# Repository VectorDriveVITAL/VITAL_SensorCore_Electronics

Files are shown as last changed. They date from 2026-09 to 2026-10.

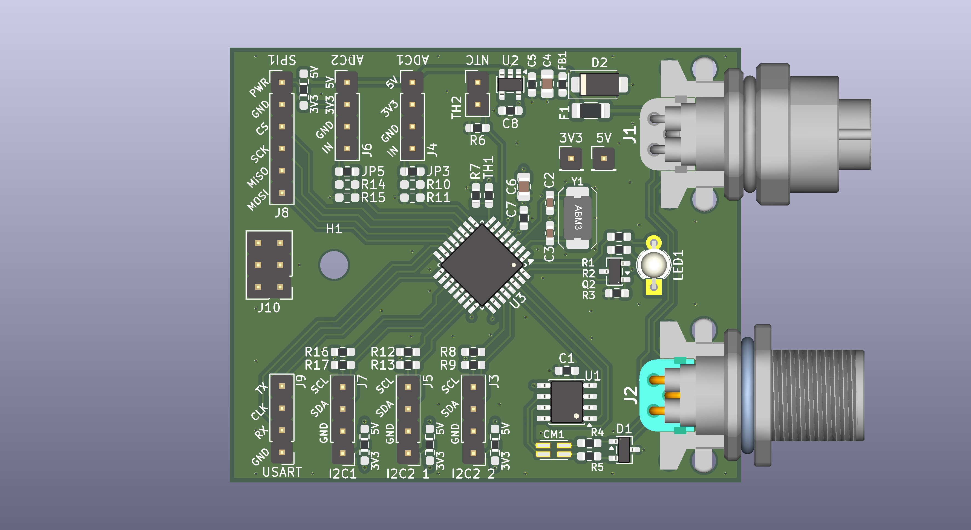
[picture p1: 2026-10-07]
SensorPack_v1/SensorPack_v1.png

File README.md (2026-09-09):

# [Project Name] — VITAL PCB Repository

Centralized repository for all PCB's for VECTOR Drive's PCB work.

## Boards

| Board | Function | Status |
|---|---|---|
| `CapstonePractice` | Practice board for planning around STM32C092 | Practice |
| `SensorCore_v1` | V1 of Sensor Core board | Schematic/PCB partially done |
| `SensorPack_v1` | V1 of Sensor Core board | Schematic partially done |

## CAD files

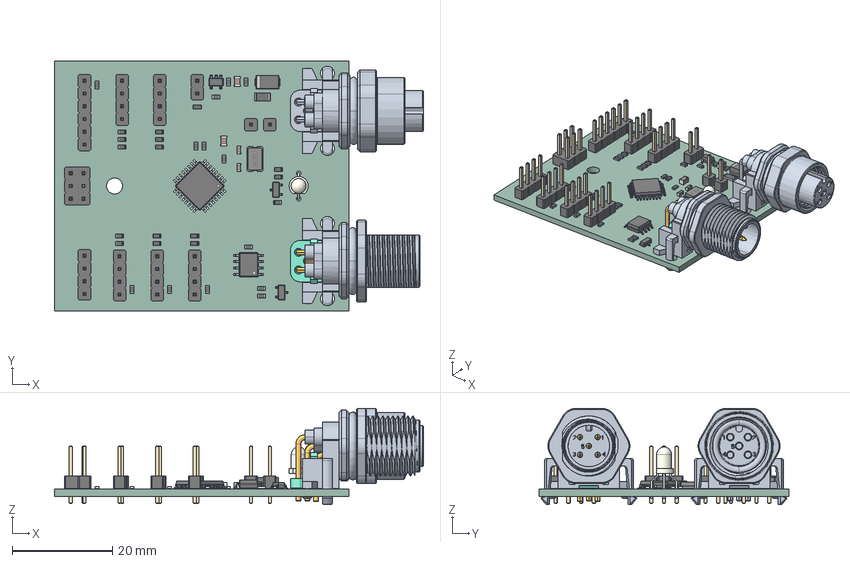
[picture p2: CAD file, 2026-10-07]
SensorPack_v1/SensorPack_v1.step
73.7 x 50.0 x 19.2 mm
R_0603_1608Metric x 29
PinHeader_2x03_P254mm_Vertical
PinHeader_1x06_P254mm_Vertical
D_SMA
SOT-23-3 x 2
PinHeader_1x04_P254mm_Vertical x 6
C_0603_1608Metric x 2
LED_D3.0mm-3
M12A-05PMMR-SF7003_SW0001
M12A-05PFFR-SF7003_SW0001
C_0805_2012Metric x 2
SOT-23-5
PinHeader_1x01_P254mm_Vertical x 2
LQFP-32_7x7mm_P0.8mm
PinHeader_1x02_P254mm_Vertical
SOIC-8_3.9x4.9mm_P1.27mm
ABM3
R_1206_3216Metric
SensorPack_v1_PCB

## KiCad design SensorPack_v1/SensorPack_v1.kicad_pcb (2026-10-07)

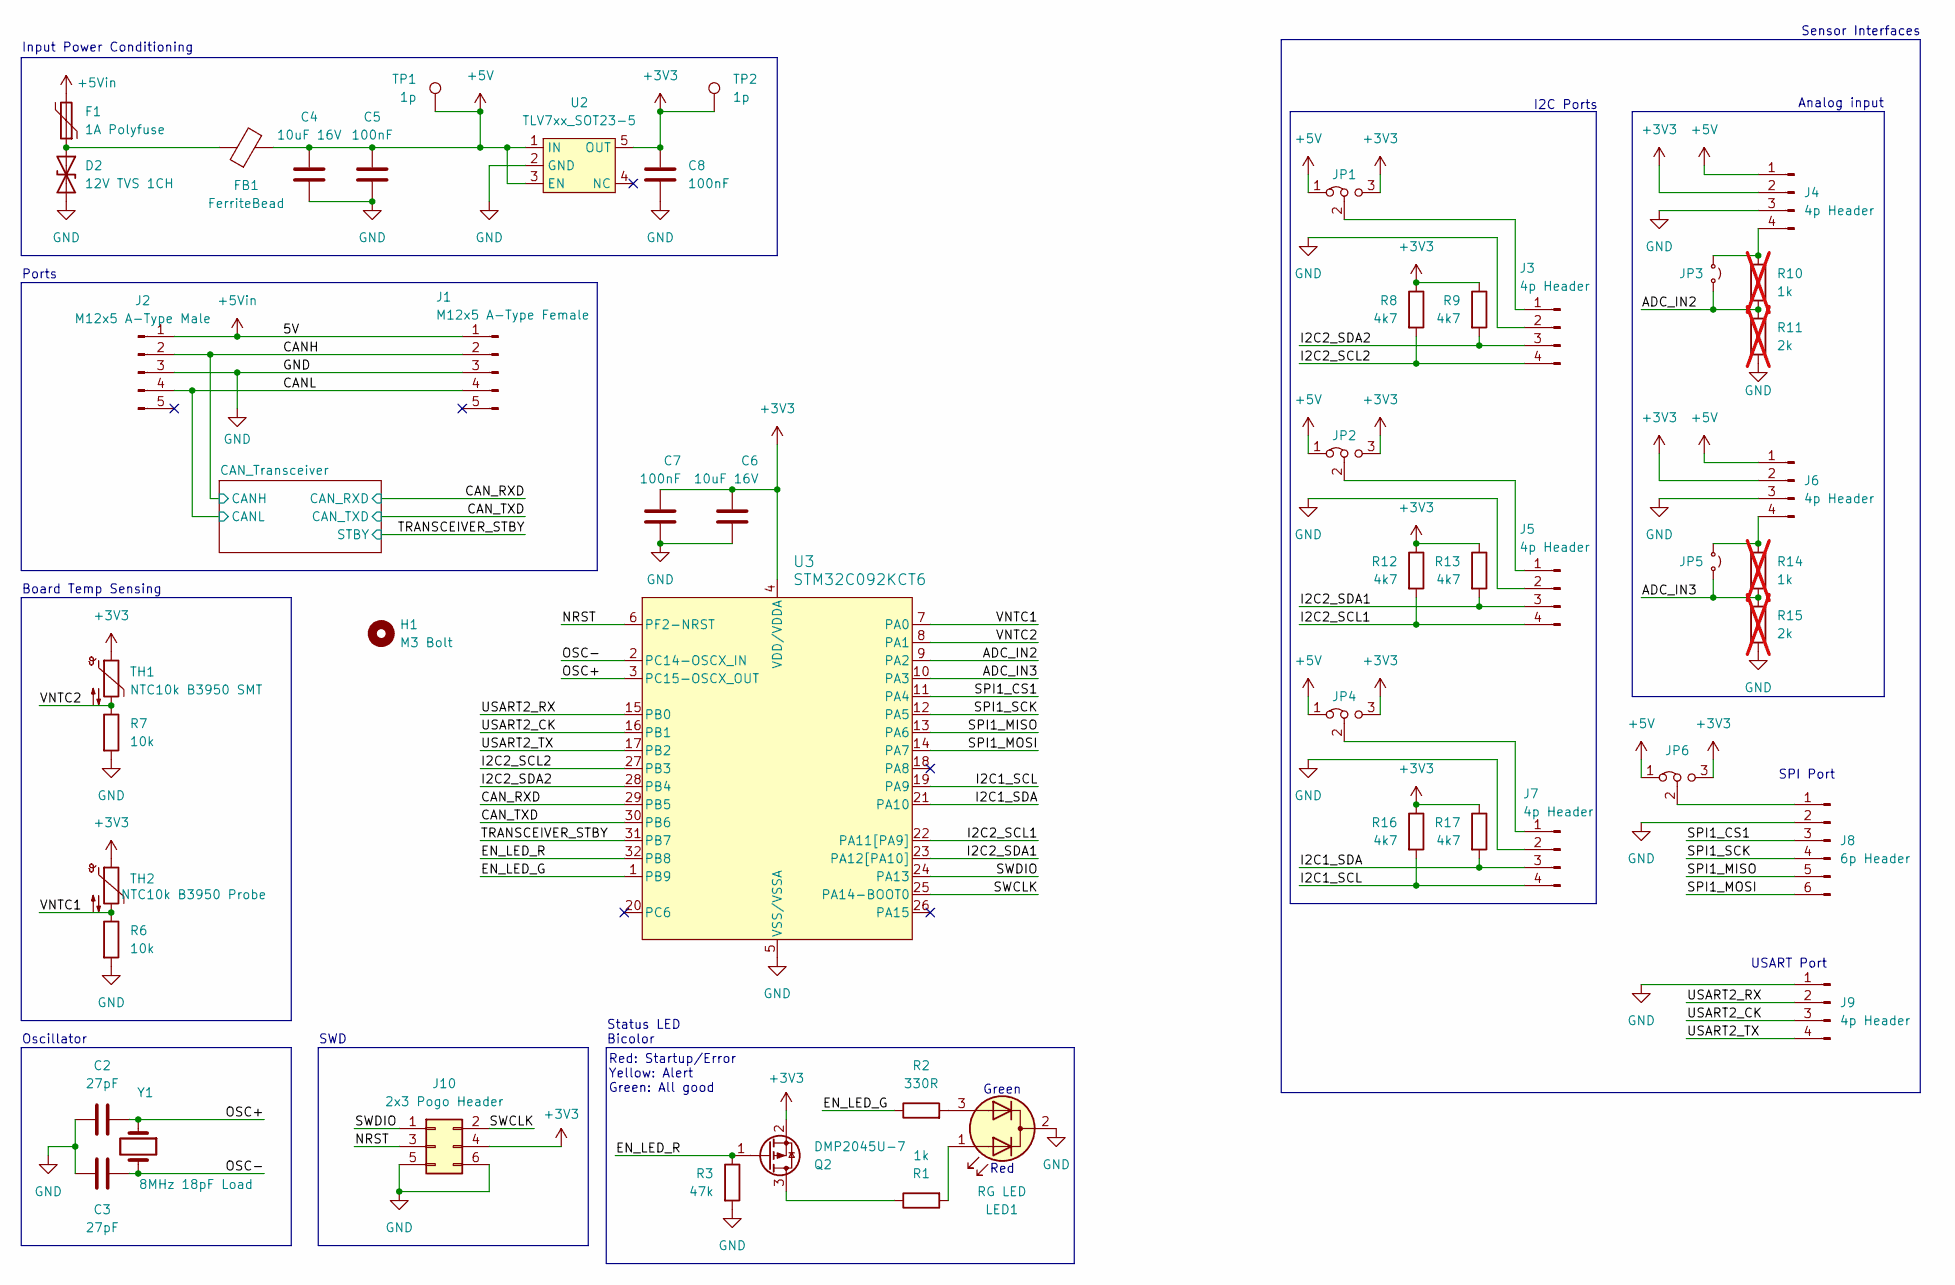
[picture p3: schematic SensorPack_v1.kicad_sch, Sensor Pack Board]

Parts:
C2, C3: 27pF; C_0603_1608Metric_Pad1.08x0.95mm_HandSolder; Digikey Part CL10C270JB8NNNC
C4, C6: 10uF 16V; C_0805_2012Metric_Pad1.18x1.45mm_HandSolder; Digikey Part CL21A106KPCLQNC
C5, C7, C8: 100nF; R_0603_1608Metric_Pad0.98x0.95mm_HandSolder; Digikey Part CL10B104KO8NNNC
D2: 12V TVS 1CH; D_SMA; Digikey Part SMAJ6.0A-13-F
F1: 1A Polyfuse; R_1206_3216Metric_Pad1.30x1.75mm_HandSolder; Digikey Part MF-NSMF050-2
FB1: FerriteBead; R_0603_1608Metric_Pad0.98x0.95mm_HandSolder; Digikey Part MPZ1608S101ATAH0
H1: M3 Bolt; MountingHole_3.2mm_M3
J1: M12x5 A-Type Female; M12A05PFFRSF7003; Digikey Part M12A05PFFRSF7003
J2: M12x5 A-Type Male; M12A05PMMRSF7003; Digikey Part M12A05PMMRSF7003
J3, J4, J5, J6, J7, J9: 4p Header; PinHeader_1x04_P2.54mm_Vertical
J8: 6p Header; PinHeader_1x06_P2.54mm_Vertical
J10: 2x3 Pogo Header; PinHeader_2x03_P2.54mm_Vertical
JP1, JP2, JP4, JP6: Jumper_3_Bridged12; Jumper_0603_2pos; Digikey Part RMCF0603ZT0R00
JP3, JP5: Jumper_2_Small_Open; R_0603_1608Metric_Pad0.98x0.95mm_HandSolder; Digikey Part RMCF0603ZT0R00
LED1: RG LED; LED_D3.0mm-3; Digikey Part WP59SURKZGW
Q2: DMP2045U-7; SOT-23-3; Digikey Part DMP2045U-7
R1: 1k; R_0603_1608Metric_Pad0.98x0.95mm_HandSolder; Digikey Part RMCF0603FT2K20
R2: 330R; R_0603_1608Metric_Pad0.98x0.95mm_HandSolder; Digikey Part RMCF0603FT4K70
R3: 47k; R_0603_1608Metric_Pad0.98x0.95mm_HandSolder; Digikey Part RMCF0603JT47K0
R6, R7: 10k; R_0603_1608Metric_Pad0.98x0.95mm_HandSolder; Digikey Part RMCF0603FT10K0
R8, R9, R12, R13, R16, R17: 4k7; R_0603_1608Metric_Pad0.98x0.95mm_HandSolder; Digikey Part RMCF0603FT4K70
R10, R14: 1k; R_0603_1608Metric_Pad0.98x0.95mm_HandSolder; Digikey Part RMCF0603FT1K00; not fitted
R11, R15: 2k; R_0603_1608Metric_Pad0.98x0.95mm_HandSolder; Digikey Part RMCF0603FT2K00; not fitted
TH1: NTC10k B3950 SMT; R_0603_1608Metric_Pad0.98x0.95mm_HandSolder; Digikey Part JSNB104J395FABXG
TH2: NTC10k B3950 Probe; PinHeader_1x02_P2.54mm_Vertical
TP1, TP2: 1p; PinHeader_1x01_P2.54mm_Vertical
U2: TLV7xx_SOT23-5; SOT-23-5; Digikey Part TLV75533PDBVR
U3: STM32C092KCT6; LQFP-32_7x7mm_P0.8mm; Digikey Part STM32C092KCT6
Y1: 8MHz 18pF Load; Crystal_6x3.5mm; Digikey Part ABM3-8.000MHZ-D2Y-T

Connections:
+3V3: C6.1, C7.2, C8.2, J4.2, J6.2, J10.4, JP1.3 (B), JP2.3 (B), JP4.3 (B), JP6.3 (B), Q2.2 (S), R8.1, R9.1, R12.1, R13.1, R16.1, R17.1, TH1.1, TH2.1, TP2.1 (1_1), U2.5 (OUT), U3.4 (VDD/VDDA); also elsewhere on the board
+5V: C4.1, C5.2, FB1.2, J4.1, J6.1, JP1.1 (A), JP2.1 (A), JP4.1 (A), JP6.1 (A), TP1.1 (1_1), U2.1 (IN), U2.3 (EN); also elsewhere on the board
+5Vin: F1.2, J1.1, J2.1
/ADC_IN2: JP3.2 (B), R10.2, R11.1, U3.9 (PA2)
/ADC_IN3: JP5.2 (B), R14.2, R15.1, U3.10 (PA3)
/CANH: J1.2, J2.2; also elsewhere on the board
/CANL: J1.4, J2.4; also elsewhere on the board
/CAN_RXD: U3.29 (PB5); also elsewhere on the board
/CAN_TXD: U3.30 (PB6); also elsewhere on the board
/EN_LED_G: R2.1, U3.1 (PB9)
/EN_LED_R: Q2.1 (G), R3.1, U3.32 (PB8)
/I2C1_SCL: J7.4, R16.2, U3.19 (PA9)
/I2C1_SDA: J7.3, R17.2, U3.21 (PA10)
/I2C2_SCL1: J5.4, R12.2, U3.22 (PA11[PA9])
/I2C2_SCL2: J3.4, R8.2, U3.27 (PB3)
/I2C2_SDA1: J5.3, R13.2, U3.23 (PA12[PA10])
/I2C2_SDA2: J3.3, R9.2, U3.28 (PB4)
/NRST: J10.3, U3.6 (PF2-NRST)
/OSC+: C2.1, U3.3 (PC15-OSCX_OUT), Y1.1
/OSC-: C3.1, U3.2 (PC14-OSCX_IN), Y1.2
/SPI1_CS1: J8.3, U3.11 (PA4)
/SPI1_MISO: J8.5, U3.13 (PA6)
/SPI1_MOSI: J8.6, U3.14 (PA7)
/SPI1_SCK: J8.4, U3.12 (PA5)
/SWCLK: J10.2, U3.25 (PA14-BOOT0)
/SWDIO: J10.1, U3.24 (PA13)
/TRANSCEIVER_STBY: U3.31 (PB7); also elsewhere on the board
/USART2_CK: J9.3, U3.16 (PB1)
/USART2_RX: J9.2, U3.15 (PB0)
/USART2_TX: J9.4, U3.17 (PB2)
/VNTC1: R6.1, TH2.2, U3.7 (PA0)
/VNTC2: R7.1, TH1.2, U3.8 (PA1)
GND: C2.2, C3.2, C4.2, C5.1, C6.2, C7.1, C8.1, D2.2 (A2), J1.3, J2.3, J3.2, J4.3, J5.2, J6.3, J7.2, J8.2, J9.1, J10.5, J10.6, LED1.2 (K), R3.2, R6.2, R7.2, R11.2, R15.2, U2.2 (GND), U3.5 (VSS/VSSA); also elsewhere on the board
unnamed: D2.1 (A1), F1.1, FB1.1
unnamed: J3.1, JP1.2 (C)
unnamed: J4.4, JP3.1 (A), R10.1
unnamed: J5.1, JP2.2 (C)
unnamed: J6.4, JP5.1 (A), R14.1
unnamed: J7.1, JP4.2 (C)
unnamed: J8.1, JP6.2 (C)
unnamed: LED1.1 (A1), R1.2
unnamed: LED1.3 (A2), R2.2
unnamed: Q2.3 (D), R1.1

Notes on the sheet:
Board Temp Sensing
Oscillator
Red
Analog input
SPI Port
SWD
I2C Ports
USART Port
Red: Startup/Error Yellow: Alert Green: All good
Sensor Interfaces
Ports
Input Power Conditioning
Status LED Bicolor
Green

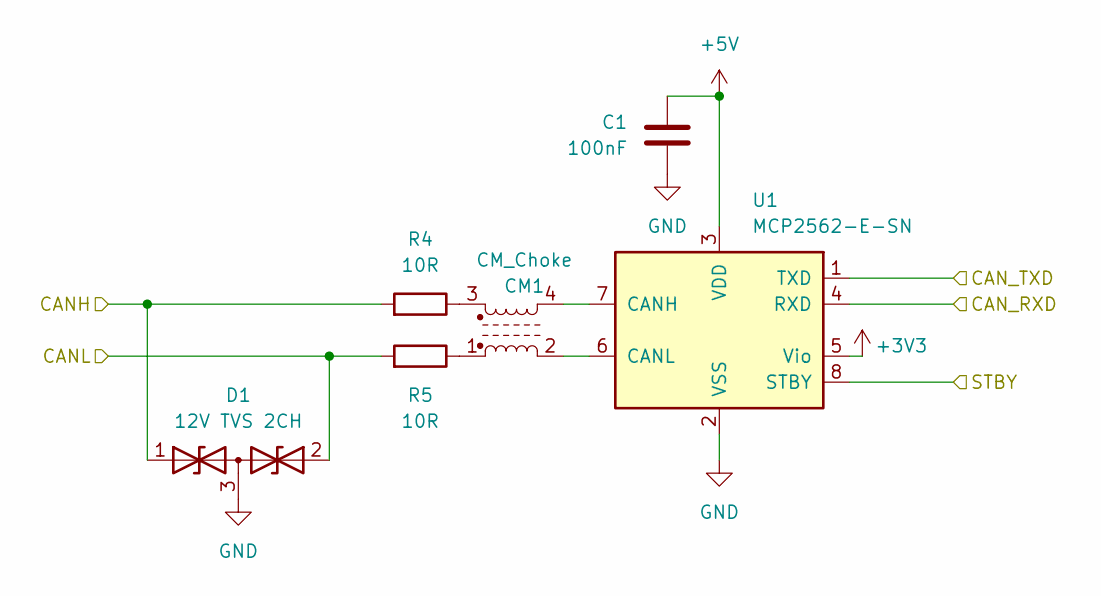
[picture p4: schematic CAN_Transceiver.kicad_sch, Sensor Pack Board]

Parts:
C1: 100nF; R_0603_1608Metric_Pad0.98x0.95mm_HandSolder; Digikey Part CL10B104KO8NNNC
CM1: CM_Choke; CMChoke_2.6x1.2mm_HandSolder; Digikey Part SCM2012FS181MDG
D1: 12V TVS 2CH; SOT-23-3; Digikey Part DESD15VL2BTQ-7
R4, R5: 10R; R_0603_1608Metric_Pad0.98x0.95mm_HandSolder; Digikey Part RMCF0603FT10R0
U1: MCP2562-E-SN; SOIC-8_3.9x4.9mm_P1.27mm; Digikey Part MCP2562-E/SN

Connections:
+3V3: U1.5 (Vio); also elsewhere on the board
+5V: C1.1, U1.3 (VDD); also elsewhere on the board
/CANH: D1.1 (A1), R4.2; also elsewhere on the board
/CANL: D1.2 (A2), R5.2; also elsewhere on the board
/CAN_RXD: U1.4 (RXD); also elsewhere on the board
/CAN_TXD: U1.1 (TXD); also elsewhere on the board
/TRANSCEIVER_STBY: U1.8 (STBY); also elsewhere on the board
GND: C1.2, D1.3 (common), U1.2 (VSS); also elsewhere on the board
unnamed: CM1.1, R5.1
unnamed: CM1.3, R4.1
unnamed: CM1.4, U1.7 (CANH)
unnamed: CM1.2, U1.6 (CANL)

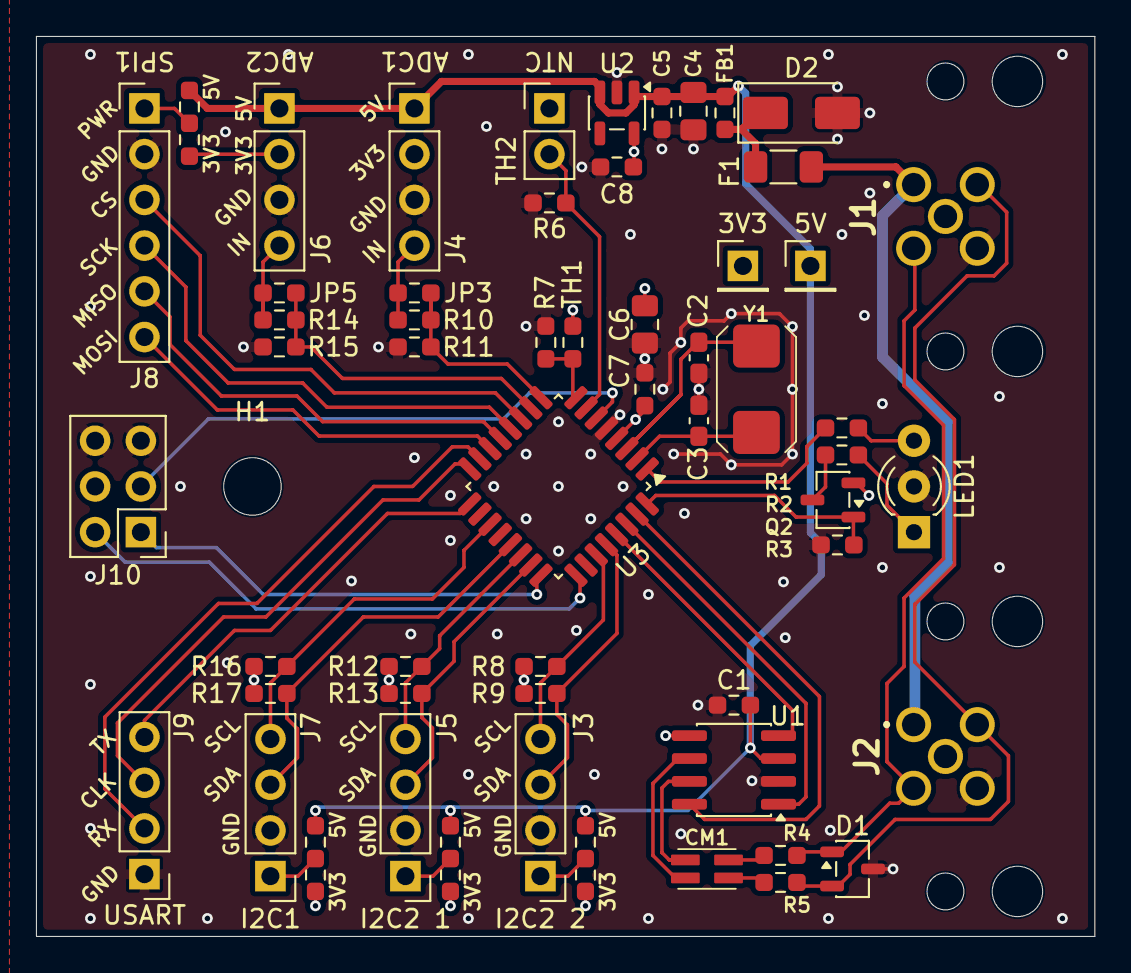
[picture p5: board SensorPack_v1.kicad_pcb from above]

Board: 4 copper layers, 58.8 x 50.0 mm, 57 parts (0 on the bottom side), 47 nets.

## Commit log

2026-09-09 Updated Readkme
    [CAN_Transceiver.kicad_sch, Power.kicad_sch, SD_Card.kicad_sch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]
2026-09-17 Featured out SensorPack_v1
    [CAN_Transceiver.kicad_sch, Power.kicad_sch, SD_Card.kicad_sch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]
2026-09-18 Sensor Pack Update
    [SensorPack_v1.kicad_pcb]
2026-09-30 Final changes to Sensor Pack
    [CAN_Transceiver.kicad_sch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]
2026-09-30 BOM changes, minor schematic change
    [SensorPack_v1.kicad_pcb, SensorPack_v1.kicad_sch]
2026-10-07 Added some mechanical notes, adjusted traces to not run under bolt (just in case), scooted top connector back in place
    [SensorPack_v1.kicad_pcb, SensorPack_v1.kicad_sch, SensorPack_v1.step]
2026-10-12 Connectors too close to edge, changed connector spacing, rearranged components appropriately
2026-10-16 SensorCore v1.0 - Approved
